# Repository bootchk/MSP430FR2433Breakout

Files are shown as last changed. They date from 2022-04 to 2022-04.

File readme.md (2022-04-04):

MSP430FR2433Breakout

A breakout board for Texas Instrument's MSP430FR2433 embedded microprocessor with Abracon RTC.

Features:

     small size
     nano power
     on board RTC to wake the MCU from deep sleep
     Tag Connect programming connector

Shared at OSHPark.  Not tested yet.

### Use case

You use a Launchpad and other breakout boards for development.
Your other breakout boards are small but the Launchpad is not.
You need a smaller version of the Launchpad.

While you can cut the Launchpad in two along its dotted line, that still leaves a 25 square centimeter board.
If weight and size are a concern, you need a smaller MSP430 breakout board.

You also want to use the MCU in low power mode LPM4.5
but you don't have an external wake up interrupt.
So you need an on board RTC to wake the MCU.

In other words, this board is a tiny motherboard with clock, for nano power applications.
You add a power supply and peripherals.

### Nano power

The use case is that the MCU sleeps mostly but wakes itself periodically.

In LPM 3 or LPM3.5, the RTC internal to the MCU wakes the MCU.
Current draw in those modes is on the order of 700nA.

To get even lower current draw, you need to use LPM4.5 with an external wakeup.
Current draw in LPM4.5 mode (with SVS disabled) is on the order of 16nA.
An external Abracon RTC to wake the MCU draws only about 25nA.
Thus the board can operate at an average current of about 50 nA.

(When SVS is disabled, you must consider what happens on brownout.
If brownout occurs, the power supply may need to discharge completely
before a proper reset occurs.
LPM4.5 with SVS enabled draws about 250nA.)

### Peripherals on board

The board has no buttons (not a reset button) or LED's

The board has an on-board external RTC.
If you don't need it, just do not populate it.
You don't need it if you don't need nano power features and can use the RTC internal to the MCU,
or you have another external interrupt.

All other peripherals such as sensors will need to be external breakout boards.

### Power

Power can be a battery.
The MSP430FR2433 MCU accepts unregulated voltage from 1.9-3.6V.

I use an energy harvesting power board and a supercapacitor.

### Pinout

The MCU has 24 pins but only 23 distinct pins (Vss is duplicated.)

Of those 23, 21 are routed to jumpers.
NotReset and Test pins are routed to the Tag Connect connector for programming by Spy By Wire (SBW.)

Three pins (P1.1, P1.2, and P1.3)
are routed to a jumper but also routed as an I2C bus and interrupt to the Abracon RTC.
If you don't populate the RTC, and don't need an I2C bus, you can use those pins for other purposes.

Jumper pins are labeled with the primary function of GPIO pins e.g. P1.0.
If you use the GPIO pins for their secondary functions, you must mentally translate the names.

The jumper pins are ordered in numerical order of name i.e. P1.0 to P3.2.
Contrast to the LaunchPad, whose pins are arranged to fit a BoosterPack standard.

### Manufacturability

In my experience, you can reliably build the board at home using a stencil for low temp solder paste and a toaster oven for reflow.

If your soldering iron tip is fine enough, you might be able to retouch some of the MCU pins.
But the footprint is NOT a hand-solderable type (with pads extending farther from the chip.)

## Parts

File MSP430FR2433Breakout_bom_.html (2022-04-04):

Source File | /home/bootch/Dropbox/solarmobile/PCBoards/MSP430Boards/MSP430FR2433Breakout/MSP430FR2433Breakout.sch
BoM Date | Sun 03 Apr 2022 11:56:12 AM EDT
Schematic Version
Schematic Date
PCB Variant | default
KiCad Version | Eeschema 5.1.7-a382d34a8~88~ubuntu16.04.1
Component Groups | 9
Component Count (per PCB) | 11
Fitted Components (per PCB) | 11
Number of PCBs | 1
Total Component Count (for 1 PCBs) | 11
 | Description | Part | References | Value | Footprint | Quantity Per PCB | Datasheet | SourcePartNo | stock
1 |  | TC2030-CTX-NL-mySchemSymbols-Blinker-rescue | CON1 | TC2030-CTX-NL | TC2030-CTX-NL | 1 |  | NA
2 | Unpolarized capacitor | C | Cby1 Cby2 | 0.1uF | C_0603_1608Metric | 2 |  | 470-9730-1-nd | 100
3 | Unpolarized capacitor | C | Cby3 | 10uF | C_0603_1608Metric | 1 |  | 490-3896-1-nd | 2
4 | Unpolarized capacitor | C | Cf1 | 47pF | C_0603_1608Metric | 1 |  | 490-1529-1-nd | 100
5 | Generic connector, single row, 01x03, script generated (kicad-library-utils/schlib/autogen/connector/) | Conn_01x03 | J3 | Conn_01x03 | PinHeader_1x03_P2.54mm_Vertical | 1 | ~
6 | Generic connector, single row, 01x12, script generated (kicad-library-utils/schlib/autogen/connector/) | Conn_01x12 | J1 J2 | Conn_01x12 | PinHeader_1x12_P2.54mm_Vertical | 2 | ~
7 |  | AB0805-mySchemSymbols-Blinker-rescue | U1 | AB0805 | QFN-16-1EP_3x3mm_P0.5mm_EP1.75x1.75mm | 1 |  | 535-11926-1-ND
8 |  | Msp430fr2433-mySchemSymbols-Blinker-rescue | U4 | Msp430fr2433 | QFN-24-1EP_4x4mm_P0.5mm_EP2.7x2.7mm_ThermalVias | 1 |  | 296-47810-1-ND
9 | Two pin crystal | Crystal | Y1 | 32.768kHz | Crystal_SMD_3215-2Pin_3.2x1.5mm | 1 | Abracon ABS07 | 535-11937-1-ND

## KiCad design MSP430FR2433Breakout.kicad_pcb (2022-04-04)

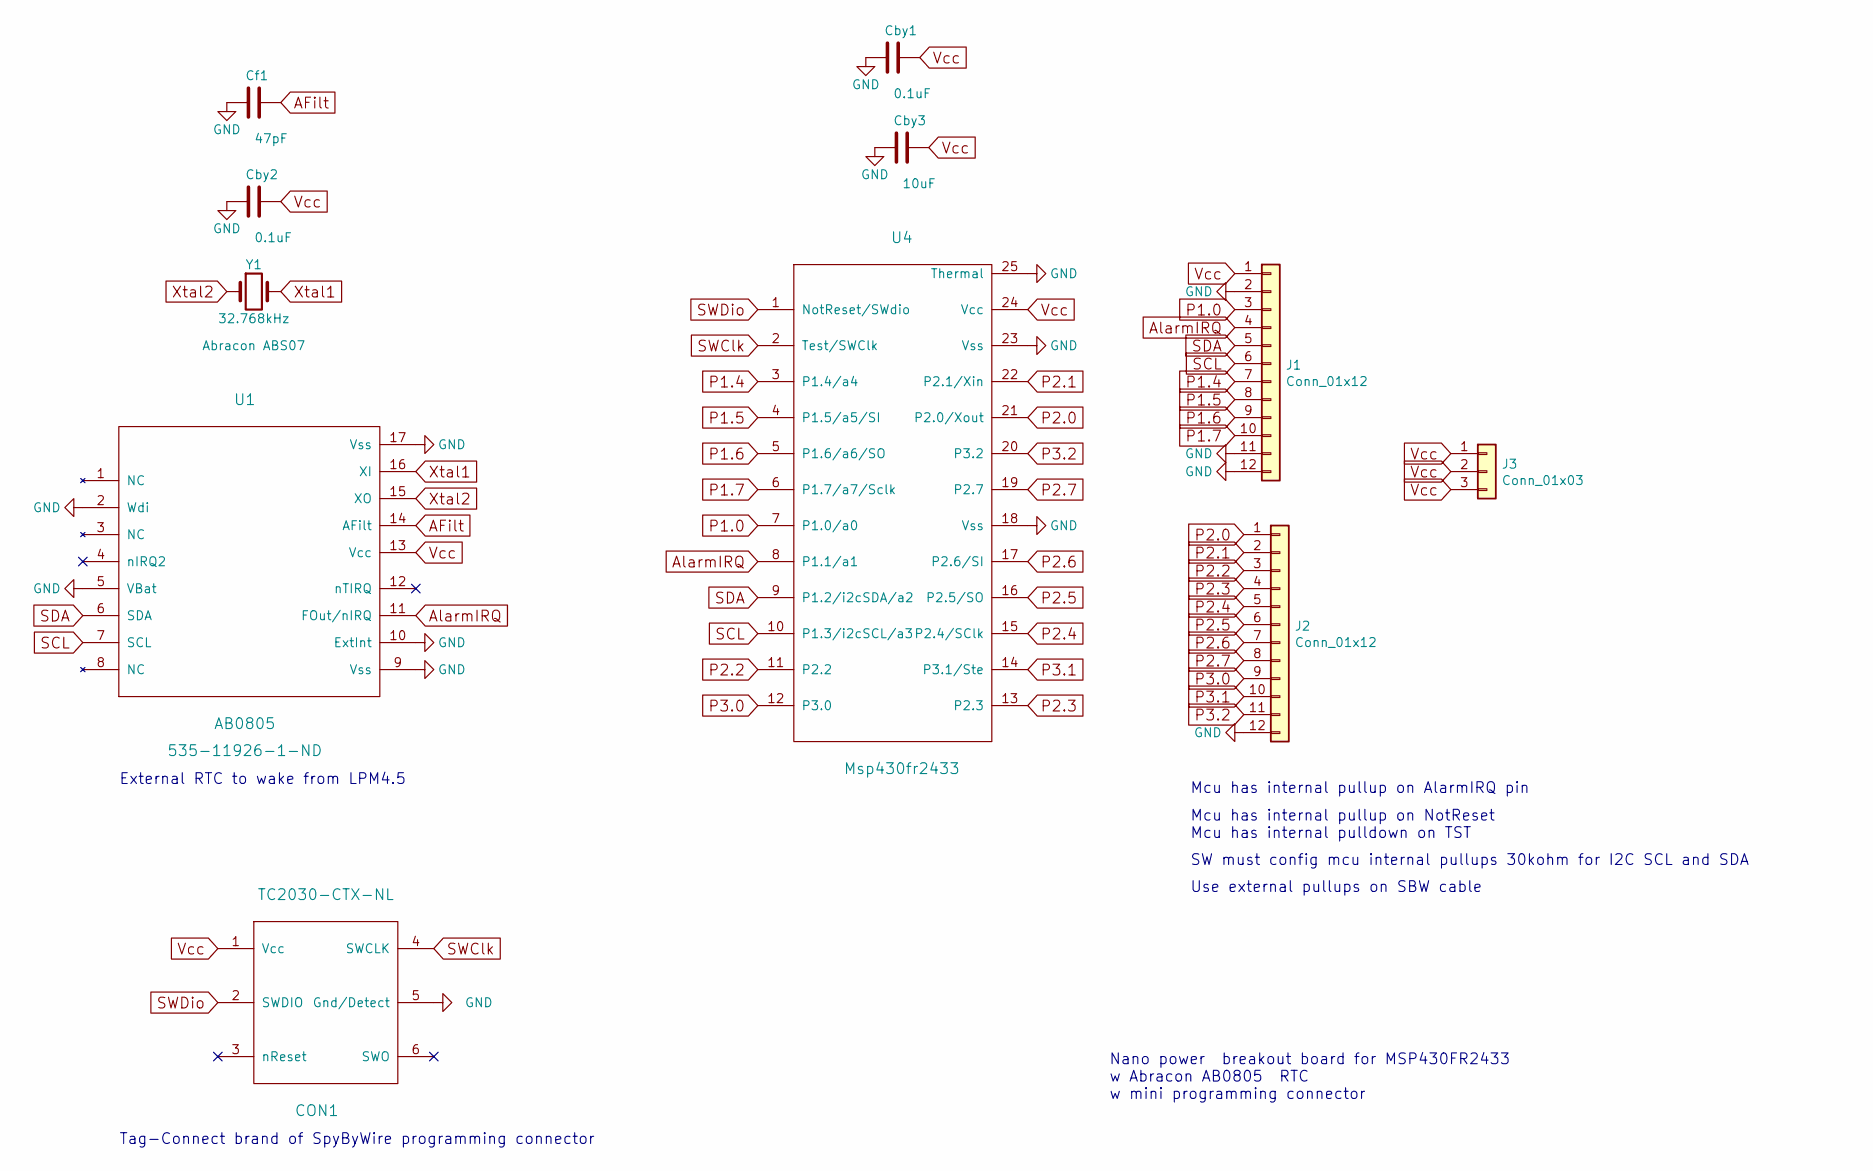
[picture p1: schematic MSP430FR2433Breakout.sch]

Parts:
CON1: TC2030-CTX-NL
Cby1, Cby2: 0.1uF; C_0603_1608Metric
Cby3: 10uF; C_0603_1608Metric
Cf1: 47pF; C_0603_1608Metric
J1, J2: Conn_01x12; PinHeader_1x12_P2.54mm_Vertical
J3: Conn_01x03; PinHeader_1x03_P2.54mm_Vertical
U1: AB0805; QFN-16-1EP_3x3mm_P0.5mm_EP1.75x1.75mm
U4: Msp430fr2433; QFN-24-1EP_4x4mm_P0.5mm_EP2.7x2.7mm_ThermalVias
Y1: 32.768kHz; Crystal_SMD_3215-2Pin_3.2x1.5mm

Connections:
AFilt: Cf1.1, U1.14 (AFilt)
AlarmIRQ: J1.4, U1.11 (FOut/nIRQ), U4.8 (P1.1/a1)
GND: CON1.5 (Gnd/Detect), Cby1.2, Cby2.2, Cby3.2, Cf1.2, J1.2, J1.11, J1.12, J2.12, U1.2 (Wdi), U1.5 (VBat), U1.9 (Vss), U1.10 (ExtInt), U1.17 (Vss), U4.18 (Vss), U4.23 (Vss), U4.25 (Thermal)
P1.0: J1.3, U4.7 (P1.0/a0)
P1.4: J1.7, U4.3 (P1.4/a4)
P1.5: J1.8, U4.4 (P1.5/a5/SI)
P1.6: J1.9, U4.5 (P1.6/a6/SO)
P1.7: J1.10, U4.6 (P1.7/a7/Sclk)
P2.0: J2.1, U4.21 (P2.0/Xout)
P2.1: J2.2, U4.22 (P2.1/Xin)
P2.2: J2.3, U4.11 (P2.2)
P2.3: J2.4, U4.13 (P2.3)
P2.4: J2.5, U4.15 (P2.4/SClk)
P2.5: J2.6, U4.16 (P2.5/SO)
P2.6: J2.7, U4.17 (P2.6/SI)
P2.7: J2.8, U4.19 (P2.7)
P3.0: J2.9, U4.12 (P3.0)
P3.1: J2.10, U4.14 (P3.1/Ste)
P3.2: J2.11, U4.20 (P3.2)
SCL: J1.6, U1.7 (SCL), U4.10 (P1.3/i2cSCL/a3)
SDA: J1.5, U1.6 (SDA), U4.9 (P1.2/i2cSDA/a2)
SWClk: CON1.4 (SWCLK), U4.2 (Test/SWClk)
SWDio: CON1.2 (SWDIO), U4.1 (NotReset/SWdio)
Vcc: CON1.1 (Vcc), Cby1.1, Cby2.1, Cby3.1, J1.1, J3.1, J3.2, J3.3, U1.13 (Vcc), U4.24 (Vcc)
Xtal1: U1.16 (XI), Y1.2
Xtal2: U1.15 (XO), Y1.1

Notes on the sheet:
Mcu has internal pullup on AlarmIRQ pin
Mcu has internal pullup on NotReset Mcu has internal pulldown on TST
SW must config mcu internal pullups 30kohm for I2C SCL and SDA
Nano power breakout board for MSP430FR2433 w Abracon AB0805 RTC w mini programming connector
Use external pullups on SBW cable
External RTC to wake from LPM4.5
Tag-Connect brand of SpyByWire programming connector

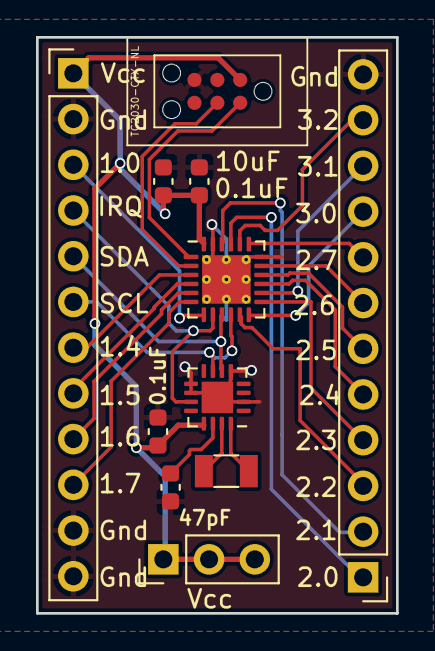
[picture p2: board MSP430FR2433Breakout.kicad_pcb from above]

Board: 2 copper layers, 20.0 x 32.0 mm, 11 parts (0 on the bottom side), 26 nets.
